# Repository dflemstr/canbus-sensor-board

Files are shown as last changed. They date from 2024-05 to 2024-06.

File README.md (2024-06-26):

# canbus sensor board

A simple board optimized for handling I²C-connected sensors and communicate the status over CAN bus.

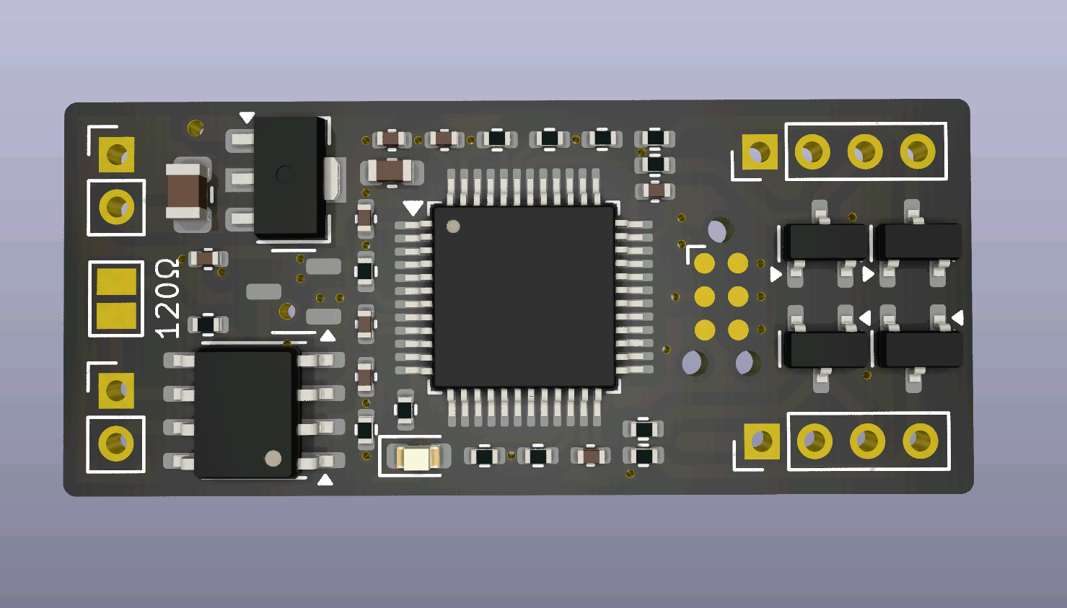
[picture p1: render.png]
PCB render


This repo contains both the PCB design files, and Rust-based firmware.

To flash and run the firmware:

  * Install Rust.  Using [rustup](https://rustup.rs/) is very strongly encouraged as it automates
    installation of cross compilation files and such.
  * Install `probe-rs`, a CLI for connecting to debug probes, with `cargo install probe-rs`.
  * Install `flip-link`, a meta-linker that puts the stack at the end of embedded memory, using
    `cargo install flip-link`.
  * Optionally update the `DEFAULT_CAN_ID` variable in `src/config.rs` if you want to change the CAN
    bus ID of the board without having to send it a command later.

Flash using a debug probe (easiest):

  * Connect the PCB to your computer using a SWD-based debug probe, for example a ST-Link v2 clone
    can be found super cheaply online, usually around $3 USD.  You can either solder wires to the
    provided pads (see PCB design files for pin assignments) or else use a TagConnect TC2030-NL
    cable, which has pogo pins matching the pads on the board, and can be bought with adapter wires
    that are compatible with an ST-Link module.
  * Run `cargo flash --release --chip STM32F103C8 --connect-under-reset` to flash to the board **or**
    run `cargo run` to flash the firmware using a debug build, start it, and stream debug logs to the
    terminal using the defmt RTT protocol. (You can of course also do any combination, e.g.
    `cargo run --release` etc)

Flash using CAN bus (more tricky perhaps):

  * Install [`can-prog`](https://github.com/marcinbor85/can-Prog), see the link for additional
    details.
  * Connect the PCB to a CAN bus.
  * Using some wires, first short the 3.3V and BOOT pads, and while still shorting the pads, also
    short the ~RST and GND pads.  This should put the board in DFU mode.
  * Build the firmware in release mode with `cargo build --release`
  * Convert the generated ELF file to a raw `.bin` file with:
    ```
    arm-none-eabi-objcopy -O binary target/thumbv7m-none-eabi/release/canbus-sensor-board image.bin
    ```

  * Run the command `canprog -f bin stm32 write image.bin -a 0x08000000` or similar. You might need
    to run `canprog stm32 erase` and such depending on the state of the firmware.

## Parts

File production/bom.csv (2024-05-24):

Designator | Footprint | Quantity | Value | LCSC Part #
C1 | 0805 | 1 | 10u >24V | C440198
C10, C5, C6, C7, C8, C9 | 0402 | 6 | 100n | C1525
C2 | 0603 | 1 | 10u >5V | C19702
C3, C4 | 0402 | 2 | 10u | C15525
D1 | 0603 | 1 | STATUS LED RED | C2286
J10, J11 | PinHeader_1x04_P2.00mm_Vertical | 2 | Conn_01x04_Socket
J2 | SolderJumper-2_P1.3mm_Open_Pad1.0x1.5mm | 1 | CAN Term
J3, J4, J5, J6, J7 | TestPoint_Pad_D1.0mm | 5 | Conn_01x01
J8, J9 | PinHeader_1x02_P2.00mm_Vertical | 2 | Conn_01x02_Socket
Q1, Q2, Q3, Q4 | SOT-23 | 4 | AO3400A | C20917
R1 | 0402 | 1 | 1k | C11702
R10, R11, R12, R13, R3, R4, R5, R6, R7, R8, R9 | 0402 | 11 | 10k | C25744
R2 | 0402 | 1 | 120 | C25079
U1 | SOT-89-3 | 1 | L78L05_SOT89 | C71136
U2 | SOT-23-3 | 1 | XC6206PxxxMR | C5446
U3 | LQFP-48_7x7mm_P0.5mm | 1 | STM32F103C8Tx | C8734
U4 | SOIC-8_3.9x4.9mm_P1.27mm | 1 | MCP2551-I-SN | C49558

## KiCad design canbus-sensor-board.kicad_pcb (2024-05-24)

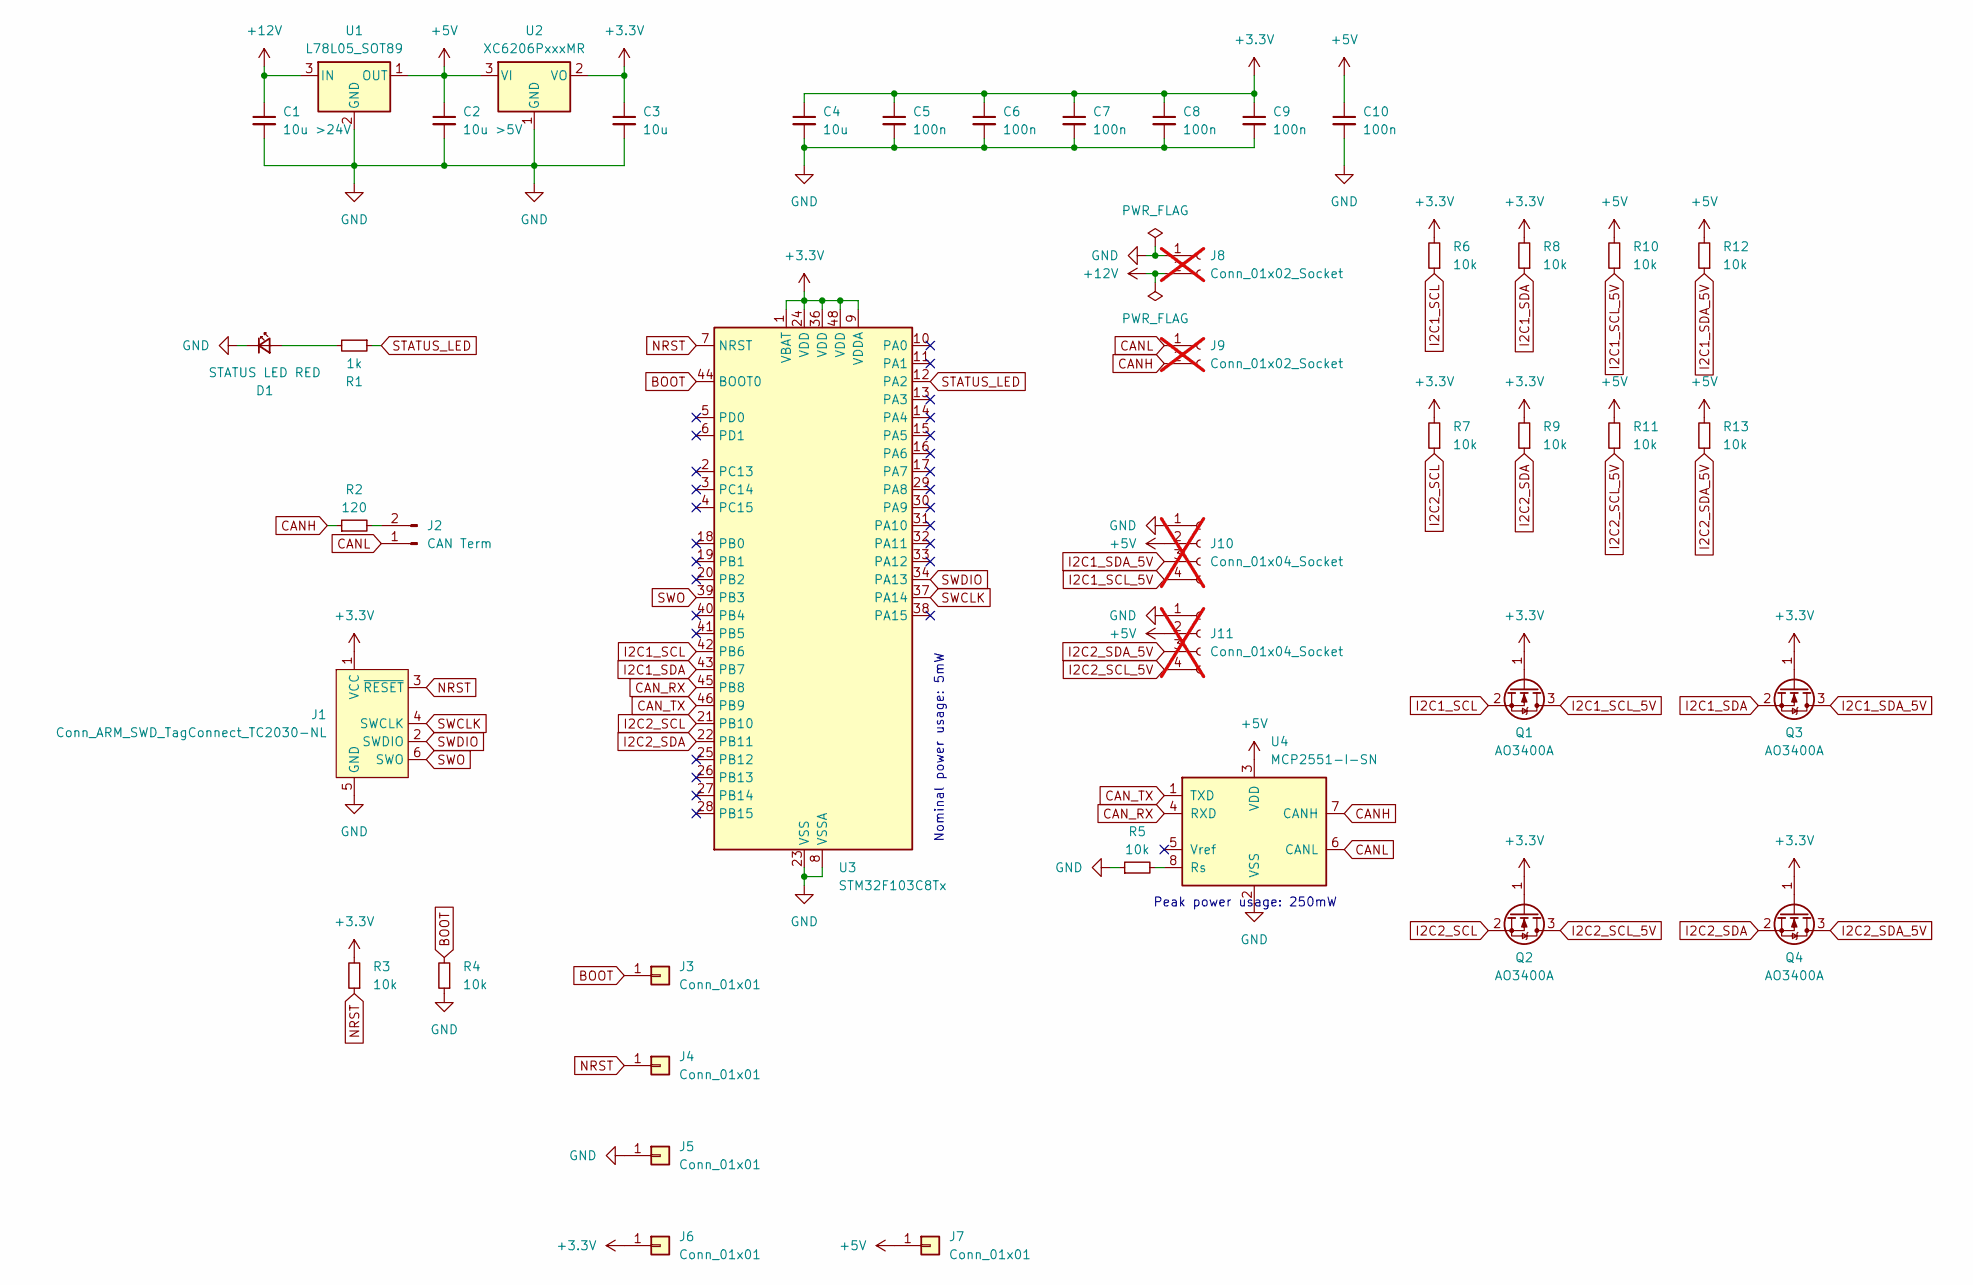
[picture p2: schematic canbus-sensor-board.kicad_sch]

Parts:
C1: 10u >24V; C_0805_2012Metric; MPN C440198
C2: 10u >5V; C_0603_1608Metric; MPN C19702
C3, C4: 10u; C_0402_1005Metric; MPN C15525
C5, C6, C7, C8, C9, C10: 100n; C_0402_1005Metric; MPN C1525
D1: STATUS LED RED; LED_0603_1608Metric; MPN C2286
J1: Conn_ARM_SWD_TagConnect_TC2030-NL; Tag-Connect_TC2030-IDC-NL_2x03_P1.27mm_Vertical
J2: CAN Term; SolderJumper-2_P1.3mm_Open_Pad1.0x1.5mm
J3, J4, J5, J6, J7: Conn_01x01; TestPoint_Pad_D1.0mm
J8, J9: Conn_01x02_Socket; PinHeader_1x02_P2.00mm_Vertical; not fitted
J10, J11: Conn_01x04_Socket; PinHeader_1x04_P2.00mm_Vertical; not fitted
Q1, Q2, Q3, Q4: AO3400A; SOT-23; MPN C20917
R1: 1k; R_0402_1005Metric; MPN C11702
R2: 120; R_0402_1005Metric; MPN C25079
R3, R4, R5, R6, R7, R8, R9, R10, R11, R12, R13: 10k; R_0402_1005Metric; MPN C25744
U1: L78L05_SOT89; SOT-89-3; MPN C71136
U2: XC6206PxxxMR; SOT-23-3; MPN C5446
U3: STM32F103C8Tx; LQFP-48_7x7mm_P0.5mm; MPN C8734
U4: MCP2551-I-SN; SOIC-8_3.9x4.9mm_P1.27mm; MPN C49558

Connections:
+3.3V: C3.1, C4.1, C5.1, C6.1, C7.1, C8.1, C9.1, J1.1 (VCC), J6.1, Q1.1 (G), Q2.1 (G), Q3.1 (G), Q4.1 (G), R3.2, R6.2, R7.2, R8.2, R9.2, U2.2 (VO), U3.1 (VBAT), U3.9 (VDDA), U3.24 (VDD), U3.36 (VDD), U3.48 (VDD)
+5V: C2.1, C10.1, J7.1, J10.2, J11.2, R10.2, R11.2, R12.2, R13.2, U1.1 (OUT), U2.3 (VI), U4.3 (VDD)
+12V: C1.1, J8.2, U1.3 (IN)
BOOT: J3.1, R4.2, U3.44 (BOOT0)
CANH: J9.2, R2.1, U4.7 (CANH)
CANL: J2.1, J9.1, U4.6 (CANL)
CAN_RX: U3.45 (PB8), U4.4 (RXD)
CAN_TX: U3.46 (PB9), U4.1 (TXD)
GND: C1.2, C2.2, C3.2, C4.2, C5.2, C6.2, C7.2, C8.2, C9.2, C10.2, D1.1 (K), J1.5 (GND), J5.1, J8.1, J10.1, J11.1, R4.1, R5.1, U1.2 (GND), U2.1 (GND), U3.8 (VSSA), U3.23 (VSS), U3.35 (VSS), U3.47 (VSS), U4.2 (VSS)
I2C1_SCL: Q1.2 (S), R6.1, U3.42 (PB6)
I2C1_SCL_5V: J10.4, Q1.3 (D), R10.1
I2C1_SDA: Q3.2 (S), R8.1, U3.43 (PB7)
I2C1_SDA_5V: J10.3, Q3.3 (D), R12.1
I2C2_SCL: Q2.2 (S), R7.1, U3.21 (PB10)
I2C2_SCL_5V: J11.4, Q2.3 (D), R11.1
I2C2_SDA: Q4.2 (S), R9.1, U3.22 (PB11)
I2C2_SDA_5V: J11.3, Q4.3 (D), R13.1
NRST: J1.3 (~RESET), J4.1, R3.1, U3.7 (NRST)
unnamed: D1.2 (A), R1.2
unnamed: J2.2, R2.2
unnamed: R5.2, U4.8 (Rs)
STATUS_LED: R1.1, U3.12 (PA2)
SWCLK: J1.4 (SWCLK), U3.37 (PA14)
SWDIO: J1.2 (SWDIO), U3.34 (PA13)
SWO: J1.6 (SWO), U3.39 (PB3)

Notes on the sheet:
Nominal power usage: 5mW
Peak power usage: 250mW

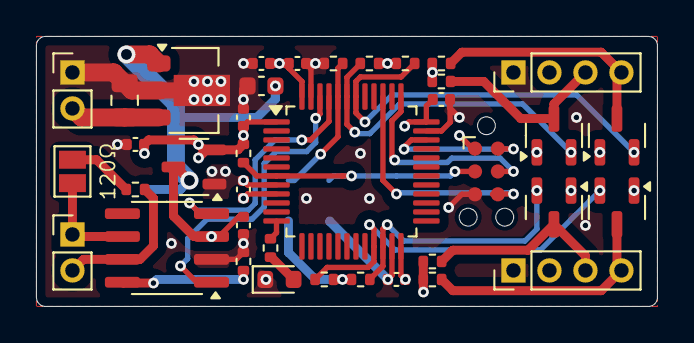
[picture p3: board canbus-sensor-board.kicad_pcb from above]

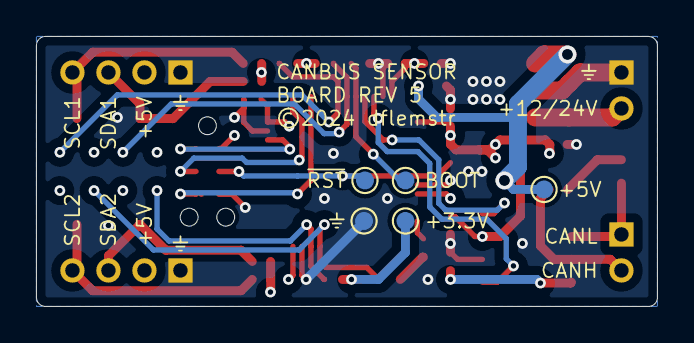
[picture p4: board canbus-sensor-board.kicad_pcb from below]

Board: 4 copper layers, 34.5 x 15.0 mm, 43 parts (5 on the bottom side), 25 nets.

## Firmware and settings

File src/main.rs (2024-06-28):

#![no_std]
#![no_main]

use embassy_stm32::{can, flash, gpio, i2c, pac, peripherals, wdg};
use embassy_sync::mutex;
// For link-time dependencies:
use {defmt_rtt as _, panic_probe as _};

mod config;
mod core;
mod leds;
mod protocol;
mod sensors;
mod status;

embassy_stm32::bind_interrupts!(struct Irqs {
    USB_LP_CAN1_RX0 => can::Rx0InterruptHandler<peripherals::CAN>;
    CAN1_RX1 => can::Rx1InterruptHandler<peripherals::CAN>;
    CAN1_SCE => can::SceInterruptHandler<peripherals::CAN>;
    USB_HP_CAN1_TX => can::TxInterruptHandler<peripherals::CAN>;
    I2C1_EV => i2c::EventInterruptHandler<peripherals::I2C1>;
    I2C1_ER => i2c::ErrorInterruptHandler<peripherals::I2C1>;
    I2C2_EV => i2c::EventInterruptHandler<peripherals::I2C2>;
    I2C2_ER => i2c::ErrorInterruptHandler<peripherals::I2C2>;
});

#[embassy_executor::main]
async fn main(spawner: embassy_executor::Spawner) {
    // Store these as static so that they get `'static` lifetime and survive when `main()` exits
    static LED: static_cell::StaticCell<leds::Led> = static_cell::StaticCell::new();
    static SENSOR1: static_cell::StaticCell<sensors::Sensor1> = static_cell::StaticCell::new();
    static SENSOR1_CHANNEL: sensors::ReadingsChannel = sensors::ReadingsChannel::new();
    static SENSOR2: static_cell::StaticCell<sensors::Sensor2> = static_cell::StaticCell::new();
    static SENSOR2_CHANNEL: sensors::ReadingsChannel = sensors::ReadingsChannel::new();
    static WDG: static_cell::StaticCell<wdg::IndependentWatchdog<peripherals::IWDG>> =
        static_cell::StaticCell::new();

    // No special requirements, e.g. no external crystal
    let p = embassy_stm32::init(embassy_stm32::Config::default());

    // Set canbus alternate pin mapping to B8/B9
    pac::AFIO.mapr().modify(|w| w.set_can1_remap(2));

    let flash = flash::Flash::new_blocking(p.FLASH);

    let led = LED.init(mutex::Mutex::new(gpio::Output::new(
        p.PA2,
        gpio::Level::Low,
        gpio::Speed::Low,
    )));

    let leds = leds::Leds::new(led);

    let can = can::Can::new(p.CAN, p.PB8, p.PB9, Irqs);

    let mut i2c_config = i2c::Config::default();
    i2c_config.timeout = config::I2C1_TIMEOUT;
    let i2c1 = i2c::I2c::new(
        p.I2C1,
        p.PB6,
        p.PB7,
        Irqs,
        p.DMA1_CH6,
        p.DMA1_CH7,
        config::I2C1_BITRATE,
        i2c_config,
    );
    i2c_config.timeout = config::I2C2_TIMEOUT;
    let i2c2 = i2c::I2c::new(
        p.I2C2,
        p.PB10,
        p.PB11,
        Irqs,
        p.DMA1_CH4,
        p.DMA1_CH5,
        config::I2C2_BITRATE,
        i2c_config,
    );

    let sensor1 = SENSOR1.init(sensors::Sensor::new(i2c1));
    let sensor2 = SENSOR2.init(sensors::Sensor::new(i2c2));

    let wdg_timeout_us = (config::WATCHDOG_TIMEOUT.as_micros() * 15 / 10) as u32;
    let wdg = WDG.init(wdg::IndependentWatchdog::new(p.IWDG, wdg_timeout_us));

    let signaller = status::LedsSignaller::new(leds, spawner);

    let core = core::Core::initialize(
        can,
        flash,
        sensor1,
        SENSOR1_CHANNEL.receiver(),
        sensor2,
        SENSOR2_CHANNEL.receiver(),
        signaller,
    )
    .await;

    wdg.unleash();

    defmt::unwrap!(spawner.spawn(poll_sensor1(sensor1, SENSOR1_CHANNEL.sender(), signaller)));
    defmt::unwrap!(spawner.spawn(poll_sensor2(sensor2, SENSOR2_CHANNEL.sender(), signaller)));
    defmt::unwrap!(spawner.spawn(run_core(core)));
    defmt::unwrap!(spawner.spawn(pet_watchdog(wdg, leds)));

    // OK, all tasks started, now we go to sleep. Purely interrupt driven from here.
}

#[embassy_executor::task]
async fn run_core(core: core::Core<'static, status::LedsSignaller>) {
    defmt::debug!("starting to run core...");
    core.run_forever().await;
}

// Need two copies of this function because it can't be generic. But they can share a generic impl
#[embassy_executor::task]
async fn poll_sensor1(
    sensor1: &'static sensors::Sensor1<'static>,
    readings: sensors::ReadingsSender,
    signaller: status::LedsSignaller,
) {
    sensor1.poll_forever(readings, signaller).await;
}

#[embassy_executor::task]
async fn poll_sensor2(
    sensor2: &'static sensors::Sensor2<'static>,
    readings: sensors::ReadingsSender,
    signaller: status::LedsSignaller,
) {
    sensor2.poll_forever(readings, signaller).await;
}

#[embassy_executor::task]
async fn pet_watchdog(
    wdg: &'static mut wdg::IndependentWatchdog<'static, peripherals::IWDG>,
    leds: leds::Leds<'static>,
) {
    let sleep_delay = config::WATCHDOG_TIMEOUT;
    let pets_per_blink_period =
        config::WATCHDOG_LED_BLINK_INTERVAL.as_micros() / sleep_delay.as_micros();
    let pets_per_led_on = config::WATCHDOG_LED_ON_DURATION.as_micros() / sleep_delay.as_micros();
    defmt::debug!(
        "starting to pet watchdog every {=u64:us}s (blink every {=u64:us}s for {=u64:us}s)",
        config::WATCHDOG_TIMEOUT.as_micros(),
        config::WATCHDOG_LED_BLINK_INTERVAL.as_micros(),
        config::WATCHDOG_LED_ON_DURATION.as_micros()
    );
    defmt::trace!("pets_per_blink_period={=u64}", pets_per_blink_period);
    defmt::trace!("pets_per_led_on={=u64}", pets_per_led_on);
    loop {
        for _ in 0..(pets_per_blink_period - pets_per_led_on) {
            wdg.pet();
            embassy_time::Timer::after(sleep_delay).await;
        }
        leds.blink_watchdog(true).await;
        for _ in 0..pets_per_led_on {
            wdg.pet();
            embassy_time::Timer::after(sleep_delay).await;
        }
        leds.blink_watchdog(false).await;
    }
}

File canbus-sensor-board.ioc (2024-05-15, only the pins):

Mcu.UserName=STM32F103C8Tx
PA12.Signal=GPIO_Output
PA13.Signal=SYS_JTMS-SWDIO
PA14.Signal=SYS_JTCK-SWCLK
PA15.Signal=GPIO_Output
PB10.Signal=I2C2_SCL
PB11.Signal=I2C2_SDA
PB12.Signal=GPIO_Output
PB3.Signal=SYS_JTDO-TRACESWO
PB6.Signal=I2C1_SCL
PB7.Signal=I2C1_SDA
PB8.Signal=CAN_RX
PB9.Signal=CAN_TX

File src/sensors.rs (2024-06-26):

use crate::{config, protocol, status};
use embassy_stm32::{flash, i2c, mode, peripherals};
use embassy_sync::blocking_mutex::raw;
use embassy_sync::{channel, mutex};

pub type Sensor1<'a> = Sensor<'a, peripherals::I2C1>;
pub type Sensor2<'a> = Sensor<'a, peripherals::I2C2>;

pub type ReadingsChannel =
    channel::Channel<raw::ThreadModeRawMutex, u16, { config::SAMPLE_BUFFER_SIZE }>;
pub type ReadingsSender =
    channel::Sender<'static, raw::ThreadModeRawMutex, u16, { config::SAMPLE_BUFFER_SIZE }>;
pub type ReadingsReceiver =
    channel::Receiver<'static, raw::ThreadModeRawMutex, u16, { config::SAMPLE_BUFFER_SIZE }>;

pub struct Sensor<'a, I2C>
where
    I2C: i2c::Instance,
{
    state: mutex::Mutex<raw::ThreadModeRawMutex, State<'a, I2C>>,
}

struct State<'a, I2C>
where
    I2C: i2c::Instance,
{
    enabled: bool,
    subscribed: bool,
    kind: Option<Driver<'a, I2C>>,
}

enum Driver<'a, I2C>
where
    I2C: i2c::Instance,
{
    Unassigned(i2c::I2c<'a, I2C, mode::Async>),
    AS5600(as5600::asynch::As5600<i2c::I2c<'a, I2C, mode::Async>>),
}

// Newtypes to enable impl of defmt::Format
#[repr(transparent)]
struct AS5600Error<E>(as5600::error::Error<E>);
#[repr(transparent)]
struct AS5600StatusError(as5600::status::Error);
#[repr(transparent)]
struct AS5600ConfigurationError(as5600::configuration::error::Error);

impl<'a, I2C> Sensor<'a, I2C>
where
    I2C: i2c::Instance,
{
    pub fn new(i2c: i2c::I2c<'a, I2C, mode::Async>) -> Self {
        let state = mutex::Mutex::new(State::new(i2c));
        Self { state }
    }

    pub async fn handle_config_msg(
        &self,
        can_message: &[u8],
        flash: &mut flash::Flash<'_, flash::Blocking>,
        flash_offset: u32,
    ) -> Result<(), protocol::ErrorCode> {
        use num_traits::FromPrimitive as _;

        if let &[sensor_kind, sensor_config, persist, ..] = can_message {
            let sensor_kind = protocol::SensorKind::from_u8(sensor_kind)
                .ok_or(protocol::ErrorCode::BadSensorKindParam)?;
            let sensor_config = protocol::SensorConfig::from_bits(sensor_config)
                .ok_or(protocol::ErrorCode::BadSensorConfigParam)?;

            if persist == 1 {
                crate::core::write_sensor_config(flash, flash_offset, sensor_kind, sensor_config);
            }

            self.configure(sensor_kind, sensor_config).await;

            Ok(())
        } else {
            Err(protocol::ErrorCode::MessageTooShort)
        }
    }

    pub async fn configure(&self, kind: protocol::SensorKind, config: protocol::SensorConfig) {
        let enabled = config.contains(protocol::SensorConfig::Enable);
        let subscribed = config.contains(protocol::SensorConfig::Subscribe);
        defmt::info!(
            "configuring sensor as kind={}, enabled={=bool}, subscribed={=bool}",
            kind,
            enabled,
            subscribed,
        );
        let mut state = self.state.lock().await;
        state.enabled = enabled;
        state.subscribed = subscribed;
        match kind {
            protocol::SensorKind::Unassigned => {
                state.make_unassigned();
            }
            protocol::SensorKind::AS5600 => {
                state.make_as5600();
            }
        }
    }

    pub async fn read_angle(&self) -> Result<u16, ()> {
        self.state.lock().await.read_angle().await
    }

    pub async fn poll_forever<S>(&self, readings: ReadingsSender, signaller: S)
    where
        S: status::Signaller,
    {
        let mut prev_angle = 0;
        let mut changed = false;
        let mut error = false;
        loop {
            let delay = if changed {
                changed = false;
                config::POLL_DELAY_CHANGED
            } else if error {
                error = false;
                config::POLL_DELAY_ERROR
            } else {
                config::POLL_DELAY_UNCHANGED
            };
            embassy_time::Timer::after(delay).await;

            let mut state = self.state.lock().await;

            if state.enabled() && state.subscribed() {
                if let Ok(angle) = state.read_angle().await {
                    if (prev_angle as i32 - angle as i32).abs() as u16
                        > config::SUBSCRIPTION_MIN_ANGLE_DELTA
                    {
                        defmt::info!("new angle value: {=u16:#x}", angle);
                        readings.send(angle).await;
                        prev_angle = angle;
                    }
                } else {
                    signaller.signal_error(status::ErrorKind::Sensors).await;
                    error = true;
                }
            }

            // Happens automatically anyway, but keeping it here as a reminder for future refactors
            // so we make sure that the lock is not kept across loop iterations.
            drop(state);
        }
    }
}

impl<'a, I2C> State<'a, I2C>
where
    I2C: i2c::Instance,
{
    fn new(i2c: i2c::I2c<'a, I2C, mode::Async>) -> Self {
        Self {
            enabled: false,
            subscribed: false,
            kind: Some(Driver::Unassigned(i2c)),
        }
    }

    fn enabled(&self) -> bool {
        self.enabled
    }

    fn subscribed(&self) -> bool {
        self.subscribed
    }

    /// Read the current sensor angle, with a range from 0x0000 to 0xffff.
    // TODO: maybe we should return some more detailed error value here
    async fn read_angle(&mut self) -> Result<u16, ()> {
        if let Some(kind) = &mut self.kind {
            match kind {
                Driver::Unassigned(_) => Err(()),
                Driver::AS5600(dev) => {
                    match dev.angle().await {
                        Ok(v) => {
                            // Convert 12 bit value to 16 bit value by padding with 4 bits
                            Ok(v << 4)
                        }
                        Err(e) => {
                            defmt::error!("could not read AS5600 angle: {}", AS5600Error(e));
                            Err(())
                        }
                    }
                }
            }
        } else {
            Err(())
        }
    }

    fn make_unassigned(&mut self) {
        self.kind = self.kind.take().map(|k| k.into_unassigned());
    }

    fn make_as5600(&mut self) {
        self.kind = self.kind.take().map(|k| k.into_as5600());
    }
}

impl<'a, I2C> Driver<'a, I2C>
where
    I2C: i2c::Instance,
{
    fn into_unassigned(self) -> Self {
        match self {
            Driver::Unassigned(i2c) => Driver::Unassigned(i2c),
            Driver::AS5600(dev) => Driver::Unassigned(dev.release()),
        }
    }

    fn into_as5600(self) -> Self {
        match self {
            Driver::Unassigned(i2c) => Driver::AS5600(as5600::asynch::As5600::new(i2c)),
            Driver::AS5600(dev) => Driver::AS5600(dev),
        }
    }
}
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

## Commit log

2024-05-04 Initial PCB design rev 1
    [bom.csv, canbus-sensor-board.kicad_pcb, canbus-sensor-board.kicad_sch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]
2024-05-13 Add rerouted PCB (possible rev 2)
    [canbus-sensor-board-rerouted.kicad_pcb]
2024-05-13 Update board to rev 3 (we do not talk about rev 2)
    [bom.csv, canbus-sensor-board-rerouted.kicad_pcb, canbus-sensor-board.kicad_pcb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]
2024-05-13 Slightly tweak some via positions
    [canbus-sensor-board.kicad_pcb]
2024-05-14 Switch to MOSFETs with lower Vgs thresholds
    [canbus-sensor-board.kicad_pcb, canbus-sensor-board.kicad_sch]
2024-05-14 Fix some broken tracks
    [canbus-sensor-board.kicad_pcb]
2024-05-15 Make I2C bitrate more clearly configurable
2024-05-22 Tweak firmware so it works on the actual device :)
2024-05-22 Further tweak rev4 of the board
    [bom.csv, canbus-sensor-board.kicad_pcb, canbus-sensor-board.kicad_sch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]
2024-05-23 Make i2c timeouts configurable
2024-05-24 Remove red LED
2024-05-24 Increase 12-24V cap size so it actually handles that voltage range
    [canbus-sensor-board.kicad_pcb, canbus-sensor-board.kicad_sch]
2024-05-24 Also make 5V cap larger to have more error margin
    [bom.csv, canbus-sensor-board.kicad_pcb, canbus-sensor-board.kicad_sch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]
2024-05-30 Increase timer resolution and use better-compressed defmt strings

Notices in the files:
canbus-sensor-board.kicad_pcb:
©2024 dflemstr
